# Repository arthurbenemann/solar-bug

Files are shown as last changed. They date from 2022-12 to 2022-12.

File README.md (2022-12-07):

# solar-bug
Based on https://github.com/rbaron/b-parasite

Screenshot from 2022-12-06 22-23-29
Screenshot from 2022-12-06 22-22-19
Screenshot from 2022-12-06 22-22-27

# License
The hardware and associated design files are released under the [Creative Commons CC BY-SA 4.0 license](https://creativecommons.org/licenses/by-sa/4.0/).
The code is released under the [MIT license](https://opensource.org/licenses/MIT).

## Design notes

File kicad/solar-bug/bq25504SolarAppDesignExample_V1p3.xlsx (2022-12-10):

User Input
Computed/Fixed
 |  |  | VSTOR nominal | 3.00 | V |  |  |  |  | VBAT_UV < VSTOR nominal <= VBAT_OV
System Loads | VOUT (V) | IOUT (mA) | Est Buck Effcy per datasheet | ISTOR = (VOUTxIOUT) / (VSTORnom x Effcy) (mA) | Mode Duration (how long?) (s) | Mode Period (how often?) (s) | Mode Hours / Day = 24 hours x duration/ period | mAHr / Day = ISTOR X Mode Hrs / Day | mWHr / Day = VSTOR x mAHr / Day
Active Mode 1 - TPS62736 VOUT | 1.800 | 0.000 | 1.000 | 0.000
Active Mode 1 - bq25504 VSTOR |  |  |  | 1.600 |  |  |  |  |  | Direct loading on VSTOR
Totals for Active Mode 1 |  |  |  | 1.600 | 1.000 | 600.000 | 0.040 | 0.064 | 0.192
Active Mode 2 - TPS62736 VOUT | 1.800 | 0.000 | 0.850 | 0.000 |  |  |  |  |  | If only one active mode, enter 0 for IOUT.
Active Mode 2 - bq25504 VSTOR |  |  |  | 0.000 |  |  |  |  |  | If only one active mode, enter 0 for ISTOR.
Totals for Active Mode 2 |  |  |  | 0.000 | 0.000 | 60.000 | 0.000 | 0.000 | 0.000
Sleep Mode - bq25504 VSTOR (1.8V rail off) |  |  |  | 0.004 |  |  | 23.960 | 0.084 | 0.252 | Idle mode hours / day = 24 minus active mode hours / day
bq25504 Iq + TPS62736 Iq + storage element leakage current |  |  |  | 0.001 |  |  | 24.000 | 0.024 | 0.072 | Storage element leaks all the time.
 | Total mAHr / day consumed |  |  |  |  |  |  | 0.172 | mAHr / day
 | Multiply by max consec dark days (e.g. not charging when overcast or raining) |  |  |  |  |  |  | 2.000 | days / week
 | Recommended minimum battery capacity |  |  |  |  |  |  | 0.344 | mAHr
 | -OR-
 | Mininum super capacitor voltage |  |  |  |  |  |  | 2.251 | V | VBAT_UV = 2.0V > Min super capacitor > VSTOR nominal
 | Maximum super capacitor voltage |  |  |  |  |  |  | 3.861 | V | VSTOR nominal < Max super capacitor voltage <= VBAT_OV
 | Recommended minimum super capacitance |  |  |  |  |  |  | 0.754 | F | Min Bat Capacity / 1000 x 3600s/hr x VSTORNOM = 1/2 x CSUPER x (Vmax2 - Vmin2)
 |  | Total mWHr / day consumed |  |  |  |  |  |  | 0.516 | mWHr / day
 |  | Multiply by operating days per week |  |  |  |  |  |  | 7.000 | days / week
 |  | Total mWHr /week required for system operation for the week |  |  |  |  |  |  | 3.609 | mWHr / week
 |  | Divide by charging days per week |  |  |  |  |  |  | 5.000 | days / week | Operating days minus max consecutive dark days
 |  | Total mWHr / day required to be collected by solar panel during charging days |  |  |  |  |  |  | 0.722 | mWHr / day | Total 7-day power must be collected during 5 charging days
 |  | Divide by charging hours / day |  |  |  |  |  |  | 6.000 | hours / day | i.e., includes excess energy for charging the battery
 |  | Instantaneous power required from the solar panel |  |  |  |  |  |  | 0.120 | mW
 |  |  | Divide by low estimate of bq25504 efficiency per datasheet |  |  |  |  |  | 0.800
 |  |  | Minimum input power required for system operation |  |  |  |  |  | 0.150 | mW
 |  |  |  | Minimum solar irradiance |  |  |  |  | 100.000 | W/m2 | Use power from lowest expected light level
 |  |  |  | Solar panel efficiency |  |  |  |  | 0.250
 |  |  |  | Minimum solar panel area required |  |  |  |  | 0.060 | cm2

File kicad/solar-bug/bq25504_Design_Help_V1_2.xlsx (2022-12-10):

User Input | VBIAS | 1.25 | V
Fixed
 | Comparator threshold for VSTOR maximum. |  |  |  |  | Comparator threshold voltages indicating when |  |  |  |  | Comparator threshold for VSTOR minimum. |  |  |  |  | Maximum power point threshold, e.g. ~0.7-0.8 of
 | Typically the max storage element voltage, |  |  |  |  | VSTOR has risen above VBAT_OK_HYS or fallen |  |  |  |  | Typically the min storage element voltage, |  |  |  |  | solar panel's open circuit voltage
 | e.g. 4.2V for LiIon battery |  |  |  |  | below VBAT_OK |  |  |  |  | e.g. 2.5V for LiIon battery
 | 2.5V < VBAT_OV < 5.25V |  |  |  |  | VBAT_OV > VBAT_OK_HYST > VBAT_UV |  |  |  |  | 2.2V < VBAT_UV < VBAT_OV |  |  |  |  | MPPT
Desired |  |  |  |  |  | RSUM1 | 12 | Mohm |  |  |  |  |  |  |  | RSUM1 | 12 | Mohm
Desired | RSUM1 | 11 | Mohm |  |  | VBAT_OK | 2.5 | V | > VBAT_UV |  | RSUM1 | 8 | Mohm |  |  | VIN_DC(OC) | 2.07 | V | Open Circuit Volts
Desired | VBAT_OV | 3.861 | V |  |  | VBAT_OK_HYST | 3.3 | V | > VBAT_OK |  | VBAT_UV | 2.2 | V |  |  | VREF_SAMP | 1.67 | V | MPP voltage
 |  |  |  |  |  |  |  | closest 1% resistor1 |  |  |  |  |  |  |  |  |  | closest 1% resistor1
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

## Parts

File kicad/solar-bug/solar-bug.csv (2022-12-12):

Item | Qty | Reference(s) | Value | LibPart | Footprint | Datasheet | DK | LCSC | MPN | Rating | Tolerance
1 | 1 | C1 | 10n | Device:C_Small | Capacitor_SMD:C_0402_1005Metric | ~ | 490-GRM1555CYA103GE01DCT-ND | C15195 |  | 35V | C0G
2 | 3 | C2, C5, C6 | 4.7u | Device:C_Small | Capacitor_SMD:C_0402_1005Metric | ~ | 490-GRM155D81C475ME15JCT-ND | C23733 |  | 6.3V | x5R
3 | 2 | C3, C4 | 12p | Device:C_Small | Capacitor_SMD:C_0402_1005Metric | ~ | 490-GRT1555C1E120JA02JCT-ND | C1547 |  |  | x5R
4 | 1 | C7 | 1.5F | Device:C_Polarized_US | solar-bug:PHVL-3R9H155-R | https://www.eaton.com/content/dam/eaton/products/electronic-components/resources/data-sheet/eaton-phvl-supercapacitor-cylindrical-pack-data-sheet-elx1022-en.pdf | 283-PHVL-3R9H155-R-ND |  | PHVL-3R9H155-R | 3.9V | x5R
5 | 1 | D1 | LED | Device:LED | LED_SMD:LED_0402_1005Metric | ~ | 754-1811-1-ND | C160479 |  |  | x5R
6 | 2 | H1, H2 | MountingHole | Mechanical:MountingHole | solar-bug:MountingHole_1.1mm | ~
7 | 1 | J1 | JLINK-6PIN | solar-bug:JLINK-6PIN | solar-bug:JLINK_6PIN
8 | 1 | L1 | 22uH | Device:L | Inductor_SMD:L_Taiyo-Yuden_NR-40xx | ~ | 587-2889-1-ND | C2880384 | NR4018T220M
9 | 1 | LOGO1 | Logo_Open_Hardware_Small | Graphic:Logo_Open_Hardware_Small | OSHW-logo:OSHW-logo_silkscreen-front_10mm | ~
10 | 3 | R1, R2, R9 | 5.23M | Device:R_Small_US | Resistor_SMD:R_0402_1005Metric | ~ | 541-5.23MLCT-ND | C477747 |  | 1/16W | 1%
11 | 2 | R3, R6 | 3.01M | Device:R_Small_US | Resistor_SMD:R_0402_1005Metric | ~ | 13-RC0402FR-073M01LCT-ND | C163464 |  | 1/16W | 1%
12 | 5 | R4, R5, R7, R10, R11 | 4.99M | Device:R_Small_US | Resistor_SMD:R_0402_1005Metric | ~ | 13-RC0402FR-074M99LCT-ND | C137963 |  | 1/16W | 1%
13 | 1 | R8 | 1k | Device:R_Small_US | Resistor_SMD:R_0402_1005Metric | ~ | 311-1.00KLRCT-ND | C11702 |  | 1/16W | 1%
14 | 4 | R12, R13, R14, R15 | 1M | Device:R_Small_US | Resistor_SMD:R_0402_1005Metric | ~ | 311-1.00MLRCT-ND | C26083 |  | 1/16W | 1%
15 | 1 | SC1 | KXOB25-04X3F-TR | Device:Solar_Cells | solar-bug:KXOB25-04X3F | https://ixapps.ixys.com/DataSheet/KXOB25-04X3F.pdf | KXOB25-04X3F-CT-ND |  | KXOB25-04X3F-TR
16 | 3 | SNS_BOT1, SNS_MID1, SNS_TOP1 | C_Variable | Device:C_Variable | solar-bug:solar-bug-sensor | ~
17 | 1 | TP1 | GND | Connector:TestPoint | solar-bug:TestPoint_Pad_D0.75mm | ~
18 | 1 | TP2 | VIN | Connector:TestPoint | solar-bug:TestPoint_Pad_D0.75mm | ~
19 | 1 | TP4 | 3V0 | Connector:TestPoint | solar-bug:TestPoint_Pad_D0.75mm | ~
20 | 1 | TP5 | VBAT | Connector:TestPoint | solar-bug:TestPoint_Pad_D0.75mm | ~
21 | 1 | U1 | E73-2G4M08S1C-52840 | solar-bug:E73-2G4M08S1C-52840 | solar-bug:E73-2G4M08S1C-52840 | https://www.ebyte.com/en/downpdf.aspx?id=445 |  | C356849
22 | 1 | U2 | BQ25504 | Battery_Management:BQ25504 | solar-bug:VQFN-16-1EP_3x3mm_P0.5mm_EP1.8x1.8mm | http://www.ti.com/lit/ds/symlink/bq25504.pdf | 296-29741-1-ND | C157471
23 | 1 | Y1 | 32.768kHz | Device:Crystal | Crystal:Crystal_SMD_MicroCrystal_CM9V-T1A-2Pin_1.6x1.0mm | https://abracon.com/Resonators/ABS05.pdf | 535-11899-1-ND | C398713

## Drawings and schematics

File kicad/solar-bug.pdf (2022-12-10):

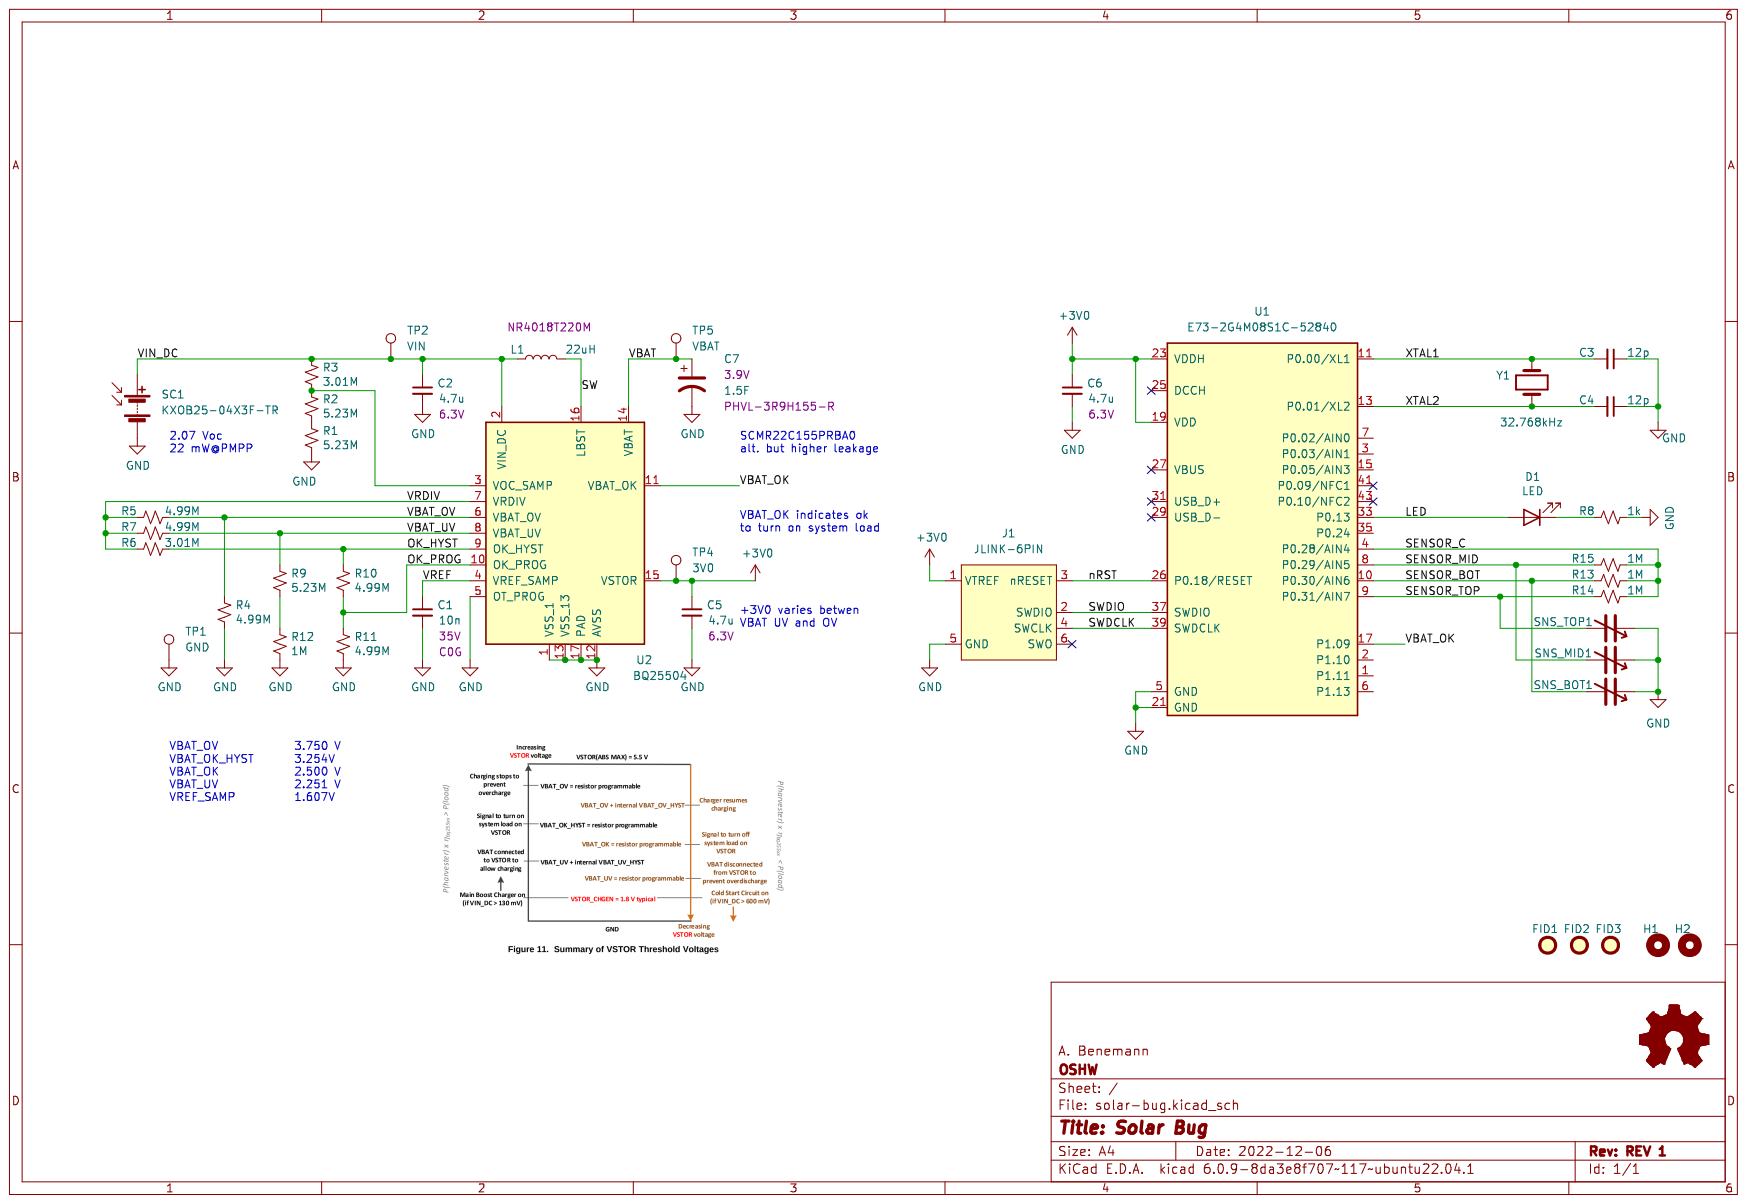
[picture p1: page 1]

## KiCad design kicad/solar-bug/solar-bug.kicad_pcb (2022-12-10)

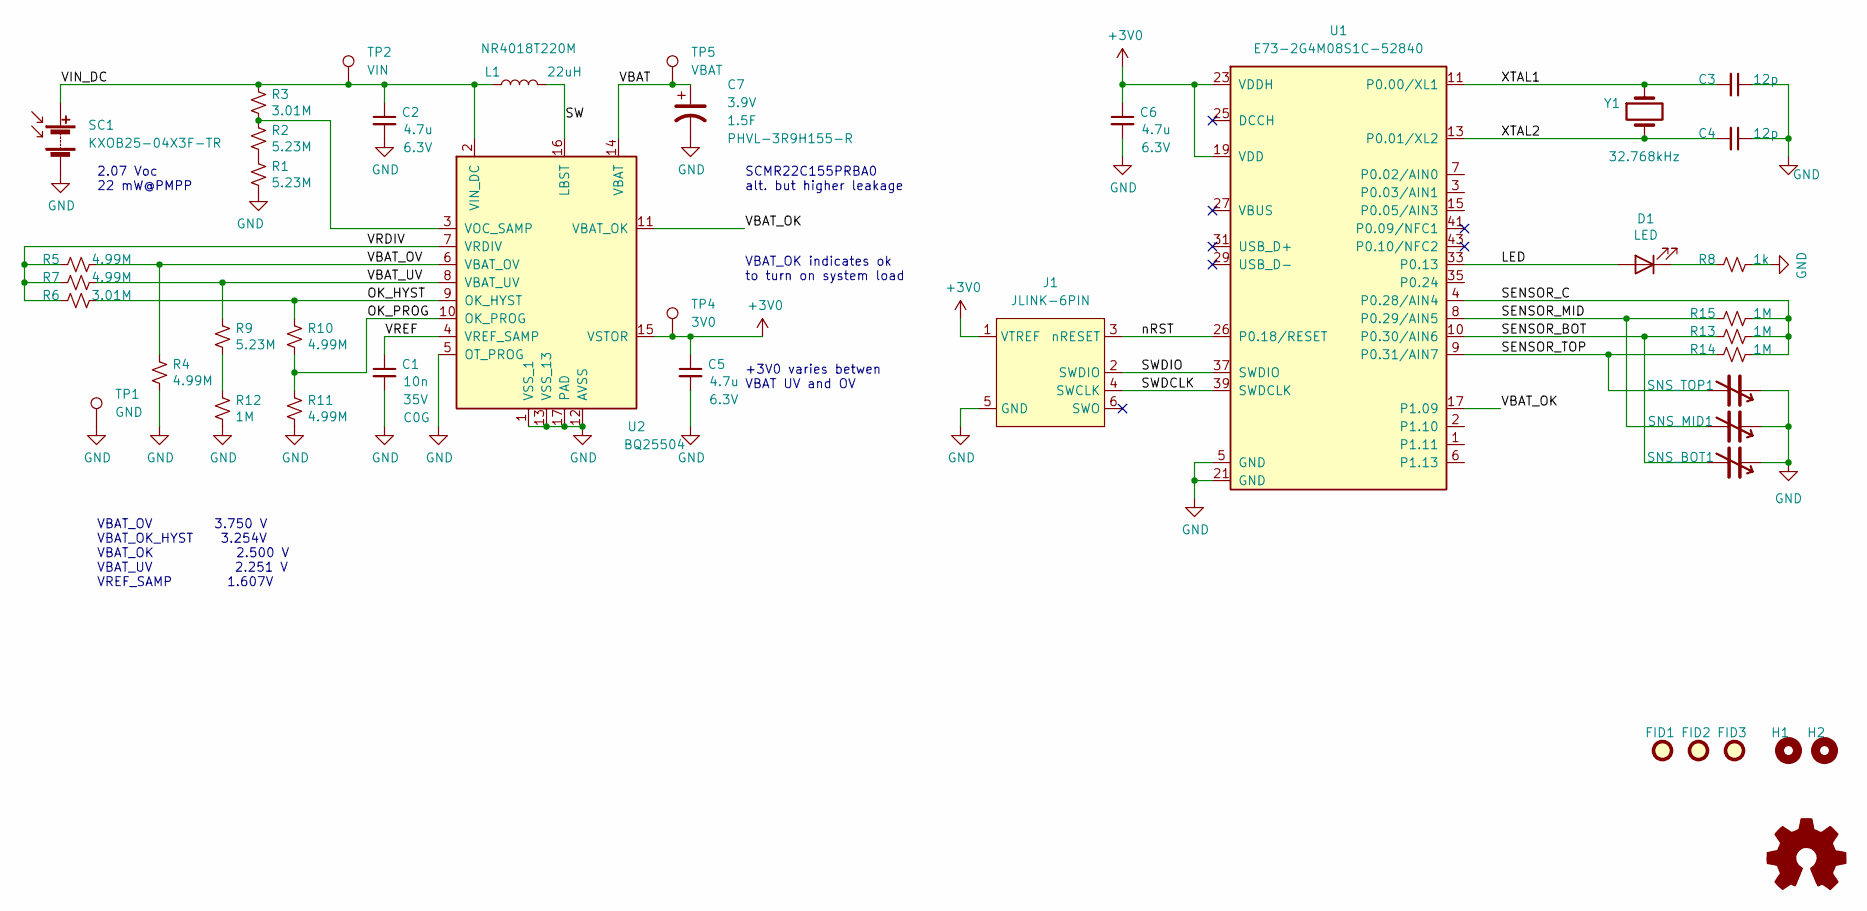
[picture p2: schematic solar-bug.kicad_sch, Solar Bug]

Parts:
C1: 10n; C_0402_1005Metric; Rating 35V; Tolerance C0G; LCSC C15195
C2, C5, C6: 4.7u; C_0402_1005Metric; Rating 6.3V; Tolerance x5R; LCSC C23733
C3, C4: 12p; C_0402_1005Metric; Tolerance x5R; LCSC C1547
C7: 1.5F; PHVL-3R9H155-R; Rating 3.9V; Tolerance x5R; MPN PHVL-3R9H155-R
D1: LED; LED_0402_1005Metric; Tolerance x5R; LCSC C160479
FID1, FID2, FID3: Fiducial; Fiducial_1mm_Mask2mm
H1, H2: MountingHole; MountingHole_1.1mm
J1: JLINK-6PIN; JLINK_6PIN
L1: 22uH; L_Taiyo-Yuden_NR-40xx; MPN NR4018T220M; LCSC C2880384
LOGO1: Logo_Open_Hardware_Small; OSHW-logo_silkscreen-front_10mm
R1, R2, R9: 5.23M; R_0402_1005Metric; Rating 1/16W; Tolerance 1%; LCSC C477747
R3, R6: 3.01M; R_0402_1005Metric; Rating 1/16W; Tolerance 1%; LCSC C163464
R4, R5, R7, R10, R11: 4.99M; R_0402_1005Metric; Rating 1/16W; Tolerance 1%; LCSC C137963
R8: 1k; R_0402_1005Metric; Rating 1/16W; Tolerance 1%; LCSC C11702
R12, R13, R14, R15: 1M; R_0402_1005Metric; Rating 1/16W; Tolerance 1%; LCSC C26083
SC1: KXOB25-04X3F-TR; KXOB25-04X3F; MPN KXOB25-04X3F-TR
SNS_BOT1: C_Variable; solar-bug-sensor
SNS_MID1: C_Variable; solar-bug-sensor
SNS_TOP1: C_Variable; solar-bug-sensor
TP1: GND; TestPoint_Pad_D0.75mm
TP2: VIN; TestPoint_Pad_D0.75mm
TP4: 3V0; TestPoint_Pad_D0.75mm
TP5: VBAT; TestPoint_Pad_D0.75mm
U1: E73-2G4M08S1C-52840; LCSC C356849
U2: BQ25504; VQFN-16-1EP_3x3mm_P0.5mm_EP1.8x1.8mm; LCSC C157471
Y1: 32.768kHz; Crystal_SMD_MicroCrystal_CM9V-T1A-2Pin_1.6x1.0mm; LCSC C398713

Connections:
+3V0: C5.1, C6.1, J1.1 (VTREF), TP4.1, U1.19 (VDD), U1.23 (VDDH), U2.15 (VSTOR)
/LED: D1.2 (A), U1.33 (P0.13)
/OK_HYST: R6.2, R10.1, U2.9 (OK_HYST)
/OK_PROG: R10.2, R11.1, U2.10 (OK_PROG)
/SENSOR_BOT: R13.1, SNS_BOT1.2, U1.10 (P0.30/AIN6)
/SENSOR_C: R13.2, R14.2, R15.2, U1.4 (P0.28/AIN4)
/SENSOR_MID: R15.1, SNS_MID1.2, U1.8 (P0.29/AIN5)
/SENSOR_TOP: R14.1, SNS_TOP1.2, U1.9 (P0.31/AIN7)
/SW: L1.2, U2.16 (LBST)
/SWDCLK: J1.4 (SWCLK), U1.39 (SWDCLK)
/SWDIO: J1.2 (SWDIO), U1.37 (SWDIO)
/VBAT: C7.1, TP5.1, U2.14 (VBAT)
/VBAT_OK: U1.17 (P1.09), U2.11 (VBAT_OK)
/VBAT_OV: R4.1, R5.2, U2.6 (VBAT_OV)
/VBAT_UV: R7.2, R9.1, U2.8 (VBAT_UV)
/VIN_DC: C2.1, L1.1, R3.1, SC1.1 (+), TP2.1, U2.2 (VIN_DC)
/VRDIV: R5.1, R6.1, R7.1, U2.7 (VRDIV)
/VREF: C1.1, U2.4 (VREF_SAMP)
/XTAL1: C3.2, U1.11 (P0.00/XL1), Y1.1
/XTAL2: C4.2, U1.13 (P0.01/XL2), Y1.2
/nRST: J1.3 (nRESET), U1.26 (P0.18/RESET)
GND: C1.2, C2.2, C3.1, C4.1, C5.2, C6.2, C7.2, J1.5 (GND), R1.2, R4.2, R8.2, R11.2, R12.2, SC1.2 (-), SNS_BOT1.1, SNS_MID1.1, SNS_TOP1.1, TP1.1, U1.5 (GND), U1.21 (GND), U2.1 (VSS_1), U2.5 (OT_PROG), U2.12 (AVSS), U2.13 (VSS_13), U2.17 (PAD)
unnamed: D1.1 (K), R8.1
unnamed: R1.1, R2.2
unnamed: R2.1, R3.2, U2.3 (VOC_SAMP)
unnamed: R9.2, R12.1

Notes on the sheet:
VBAT_OK indicates ok to turn on system load
2.07 Voc 22 mW@PMPP
VBAT_OV 3.750 V VBAT_OK_HYST 3.254V VBAT_OK 2.500 V VBAT_UV 2.251 V VREF_SAMP 1.607V
+3V0 varies betwen VBAT UV and OV
SCMR22C155PRBA0 alt. but higher leakage

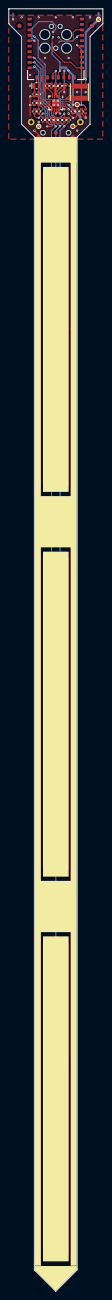
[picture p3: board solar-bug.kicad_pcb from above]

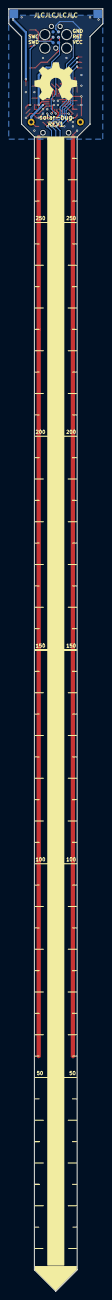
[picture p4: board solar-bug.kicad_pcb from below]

Board: 2 copper layers, 22.0 x 300.0 mm, 42 parts (4 on the bottom side), 26 nets.

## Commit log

2022-12-10 Cleared remaining DRC, add JLCPCB part numbers
    [bq25504_Design_Help_V1_2.xlsx, parasite.kicad_pcb, parasite.kicad_sch]
2022-12-10 clean-up folder, renamed project file
    [bq25504SolarAppDesignExample_V1p3.xlsx, bq25504_Design_Help_V1_2.xlsx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]
2022-12-12 Add Digikey PNs to BOM, generate BOM CSV
    [solar-bug.csv, solar-bug.kicad_sch]
